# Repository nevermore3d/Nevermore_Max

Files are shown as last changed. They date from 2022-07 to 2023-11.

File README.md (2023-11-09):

<!--
*** Thanks for checking out the Best-README-Template. If you have a suggestion
*** that would make this better, please fork the repo and create a pull request
*** or simply open an issue with the tag "enhancement".
*** Thanks again! Now go create something AMAZING! :D
-->

<!-- PROJECT SHIELDS -->
<!--
*** I'm using markdown "reference style" links for readability.
*** Reference links are enclosed in brackets [ ] instead of parentheses ( ).
*** See the bottom of this document for the declaration of the reference variables
*** for contributors-url, forks-url, etc. This is an optional, concise syntax you may use.
*** https://www.markdownguide.org/basic-syntax/#reference-style-links
-->
# [Nevermore Stealthmax](https://github.com/nevermore3d/StealthMax) is the final Max release based on beta feedback, Please check it out!

Max had warping issues with many ABS type materials from the long straight components, which necessitated a frame redesign. This allowed for a built-in exhaust system too driven by the main fan, allowing well-insulated chambers not to overheat when printing PLA and PETG.

<BR><BR><BR><BR><BR><BR>
_300x300mm print bed minimum!_

**0.2 layers, 0.4 nozzle recommended [0.6+Aarachnae under evaluation]**

PRINTING GUIDE:

**FRAME:**

VERY WARP-PRONE WITH STANDARD ABS! Even if you never have warping issues otherwise, this is at the very edge of plastics cooling stresses. I have printed this successfully with TitanX, other users have had good results with ESun ABS+. As it will never be subject to PETG TG temperatures outside the chamber that can be a good option too. Extra adhesion precautions should be taken (lower z offset with horizontal compensation, nano adhesive, hotter bed or possibly chamber temps, etc). Also dont forget to **tape down your flex bed** or your flex bed may become the warping point instead.

**PANELS**

Panels have A LOT of surface area. If you do not use filament that pops off from the bed when cool - a need to flex your bed to remove parts - there is a certain risk that a thin PEI surface (0.15-0.30 mm thicknesses or therabouts) will be pulled off in spots with high adhesion, causing bubbles in your PEI. If you have thin PEI, or any other thin surface that can be damaged, please use a release layer between the print and bed (my simple household go-to for PEI+ABS is some corn starch dissolved in water and evaporated after being brushed onto the hot bed. Parts will release easily and any starch residue on the print or bed just washes off with water).

**Carbon Baskets**

The unbridged mesh extrusions keeping the pellets inside the filter are usually 0.4mm high and 0.8mm wide. They print best if the width is split in two lines (with some overlap, 0.4-0.46 should do it, check in your slicer) and the height is also split in two layers (allowing the first layer to be printed at a slightly lower extrusion multiplier as per bridging settings, and the second be a regular supported layer).

**Other parts**
The other parts should print like most other prints. 

**9/9: INSTALL GUIDE ADDED**
<!-- PROJECT LOGO -->
<br />
<p align="center">
  <https://github.com/0ndsk4/VoronUsers/tree/0ndsk4/printer_mods/0ndsk4/Nevermore_Air_Filter">
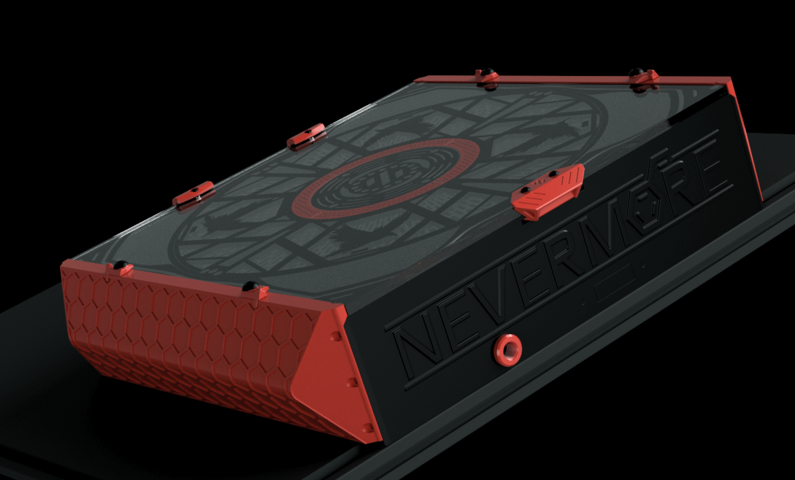
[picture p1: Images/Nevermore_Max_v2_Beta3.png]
    
							   <p align="center">
  <https://github.com/0ndsk4/VoronUsers/tree/0ndsk4/printer_mods/0ndsk4/Nevermore_Air_Filter">
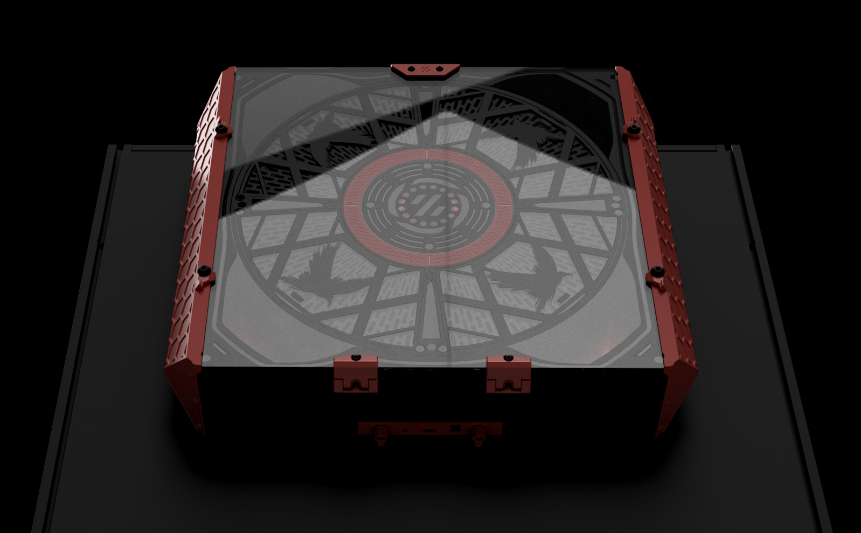
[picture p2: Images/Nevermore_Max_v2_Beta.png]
Angle
    
	  <p align="center">
  <https://github.com/0ndsk4/VoronUsers/tree/0ndsk4/printer_mods/0ndsk4/Nevermore_Air_Filter">
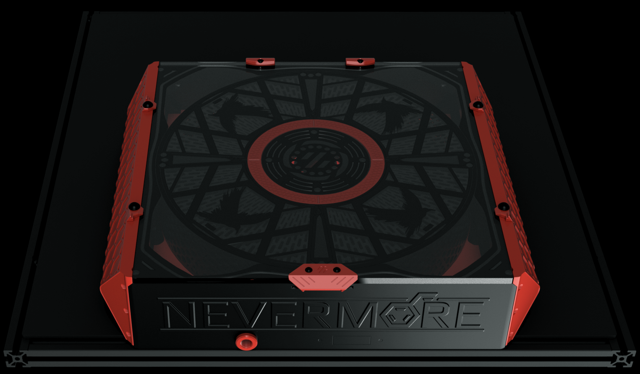
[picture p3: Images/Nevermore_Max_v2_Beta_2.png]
Angle2
    
  </a>

  <h3 align="center">Nevermore Max 3D printer Air Filter</h3>

<!-- TABLE OF CONTENTS -->
<details open="open">
  <summary>Table of Contents</summary>
  <ol>
    <li>
      <a href="#About-The-Nevermore">About: Why a Nevermore Max?</a>
      <ul>
        <li><a href="#Why">Why Nevermore?</a></li>
		<li><a href="#But-we-already-have-a-filtered-exhaust">But we already have a filtered exhaust?</a></li>
		<li><a href="#I-have-worked-with-plastics-and-I-am-fine">I've worked with plastics, and I'm fine!</a></li>
      </ul>
    </li>
    <li>
      <a href="#getting-started">Getting Started</a>
      <ul>
        <li><a href="#BOM">BOM and Sourcing Guide</a></li>
        <li><a href="#installation">Installation</a></li>
		<li><a href="#Built-with">Built with</a></li>
      </ul>
    </li>
    <li><a href="#contributing">Contributing</a></li>
    <li><a href="#license">License</a></li>
  </ol>
</details>

<!-- ABOUT THE PROJECT -->
## About Nevermore Max

Why a Max when the Micro works well? The little bugger is an easy print, nimble, looks great... Why bother making a large unit chewing filament?
			 
	 Well - there are a few reasons, that may or may not affect your decision on what filter is best for you.
			  
	1. We're **LAZY**. A micro cartridge is small and may not last very long. Some will 
	have filament smell again in two weeks.   And while the change is quick and easy,
	its still a chore! A Max has 20x the carbon. 20x the carbon lasts...longer.  
	
	2. We need **BETTER**. Carbon filtration gets better and better the deeper the carbon 
	bed. At the small airflow area of a micro, a deep bed quickly chokes air flow. 
	Ever wondered why a Micro XL cartridge is only 10mm longer than a standard cartridge? 
	Air flow degrades _that_ fast. The surface area of a micro cartridge is just 
	above 1000 mm2. A hefty max filter increases that over ten times at the inside 
	perimeter, and 50 times on the outside perimeter. This means the same powered
	fan could move _much_ more air at _less_ pressure drop.  
	
	3. We catch **PARTICLES**: 3D printer extrusion creates both VOCs and particles. 
	The micro focuses on VOCs, as thats what give off the worst smell and has direct 
	toxic effects, and are difficult to catch once outside of the print chamber. 
	Yet again, PM particles are among the leading causes of death in the world and 
	shouldn't be ignored. I've advocated using a regular room-size HEPA for particles 
	in conjunction with a micro before, but with the Max a HEPA filtration system is
	 built in. 99+ per cent of particles created by your printer will be removed 
	 every pass and you wont add dirty air to your room or lungs.  
	 
	4. We need **COOLER**: 3D printing and 3D printing filtration require different things.
	For instance, we _love_ to have a 60C chamber for less ABS warping. At the same
	time, with increasing heat, the VOCs get more heat energy and desorb from the 
	carbon. Sensor testing has shown that turning on a well used carbon filter can 
	_increase_ chamber VOCs. Anything above 50C is generally not good for bads stuff to
	stay attached to the carbon. And while the micro has been shown to work even at 
	80C intake air under a heated bed, it most definitely decreases the time between 
	carbon changes a lot! Having the filter unit outside of the printer allows for the
	carbon to be a few degrees cooler than the printer. That does much for longevity.  
	   
	5. We haz to needz **TECHz**: More space for cooler gadgets. Ever wondered when 
	its time to swap carbon? Well, on the max you could add VOC sensors to both intake
	and exhaust and measure how well the filter is doing its job! Thanks to Dr Dave
	there are even data on which sensors reliably detect the aromatic VOCs we strive
	to catch (a lot of sensors hardly detect extrusion VOCs at all as they are intended
	for other applications). I've chosen to divide the project into a Basic version
	with just HEPA+carbon+fan, but entirely upgradeable to the Pro version 
	including VOC sensors (temp, humidity, filter efficiency), LED/Screen
	/Controller board, servo carbon sealing for (optimal carbon longevity with no
	room VOC carbon depletion) and a 4010 exhaust (negative pressure+vent 
	control).  

	7. Less **NOISE**: Lets face it. A high powered 5015 creates some noise. Two creates
	even more. By increasing the size of the carbon filter, decreasing pressure drop,
	we can run the filter fan slower while still getting the same air flow. We can 
	run the fan at a higher rpm:s and clean the chamber in a jiffy as well.  
			    
			  Convinced? Well, then the Max is for you!	

<!-- GETTING STARTED -->
## Getting Started

You're ready to build a Nevermore? Cool! The New Max is a lot simpler to assemble compared to the first version!

### BOM and Sourcing Guide
For the sourcing guide, details and material list please check this out: [BOM](BOM.md)

Instead of ultra thin bolts, m3 lap top screws seems to work as well and are readily available (https://www.ebay.com/itm/185540026013?var=693379492797)

### Installation
The installation guide is under development, the alpha presentation  should take you 90% of the way:
[Installation Guide](https://www.canva.com/design/DAFLeYZF86Y/dYEmVobjTJoAHgrsha3OjA/view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)

### Built with
The Voron nevermore Air Filter was modelled in [Fusion 360](http://autodesk.com).

<!-- USAGE EXAMPLES -->

### Why

At the end of the day, a fresh single-pass filtered exhaust (at brand new) has perhaps 70% VOC removal efficiency while still exhausting 30% of the nasty into the air you breathe. A recirculation filter achieving four passes at worn-in 50% efficiency could still remove 94% of the bas stuff. Or 99% at six passes!

The number of passes you get all depends on how well you can seal your build chamber. The better sealed the chamber, the less room VOCs will circulate the carbon and deplete the filter too (VOCs from onions, wall paper or farts might not be as unhealthy as melted plastics VOCs, but they block space in the carbon all the same).

Some will have a hard time achieving a good chamber seal, which creates the biggest drawback of recirculation filters - they're air flow neutral. Meaning, as nothing pulls air into the chamber, air can diffuse freely to the outside through any remaining gaps. And that air could be <i>zero per cent</I> cleaned...

To both have the cake and eat it (yes you can!), a Max can incorporate a 4010 exhaust fan, that is used to keep a slight negative pressure inside the chamber - air will still just get pulled _into_ the chamber through any remaining cracks, not leak outside. Don't ramp it up high, its meant to just barely evict air so that the majority of air flow through the filter is still recirculated.

Air evicted through the exhaust will at least have passed through the carbon filter, dust-filter and HEPA filter at least once (hopefully many more times) - so its a good security measure to have if you don't want to bet on your chamber being hermetically sealed.

### But we already have a filtered exhaust?

Yup, but aside from being one-pass, regular mesh carbon filters mainly consists of...mesh. And active carbon sprinkle - miniscule amounts, not meant to be used 24/7 in a 3d printer.

Just running regular  air through a mesh filter will still deplete it in weeks (carbon can't opt to just bind the nasty stuff). Filter exposed to air depletes it too, in time. Friggin' everything depletes carbon. Thats why we need *more*.

<b>The Nevermore</B> has a <i>kilo</i>, or two pounds, of active carbon. Not single-digit grams. And its can be sealed off from the surroundings, so when its not running, its not depleting. Any off-gassing between prints will likewise be kept inside the filter! And when is does run, it has a lot of VOC binding capacity! At least a hundred times more compared to a generic solder fume carbon mesh filter. 

This is the filter for the low maintenence crowd (who still want to be safe).

### I have worked with plastics and I am fine!

If you live alone - not impacting other people – and feel that way, this filter is not for you! <br>
After all, you’re perfectly allowed to smoke two packs a day or become a opposition politician in Russia too, even though it’s probably not optimal for your health. And on an individual level one can never be sure what the health effects will be, if any - the oldest person ever used to smoke until she was 118 years or so…

But speaking of what we do know, we can say for sure that:<BR>

The WHO:s <I>International Agency for Research of Cancer (IARC)</i> classifies chemical compounds based on the known evidence of human carcinogenics, into four classes (<I>carcinogenic, probably carcinogenic, possibly carcinogenic or not classifiable as carcinogenic to humans</i>).<BR><BR>
Most chemicals fall into the last category, but in the known carcinogenic groups we find several known 3d printer byproducts:<br><br>
&nbsp;&nbsp;&nbsp;&nbsp;&nbsp;&nbsp;&nbsp;<B>o Benzene</b><BR>
One of the main fumes from ABS printing. 3ppm regarded as safe, whereas up to 280 ppm of VOCs are produced ABS printing every hour in a small space. Proven to cause different leukemias, and suspected of causing a multitude of other cancers. Female workers in a shoe factory exposed to 40ppm for a long time had a hundredfold higher risk of dying from breast cancer, for instance. Class 1 carcinogenic.<br><BR>
&nbsp;&nbsp;&nbsp;&nbsp;&nbsp;&nbsp;&nbsp;<b>o Styrene</B><BR>
Main pollutant in ABS fumes, recently upgraded from possible to probable carcinogenic based on mounting evidence of connection with a close to tripled risk of different leukemias.<br><BR>
&nbsp;&nbsp;&nbsp;&nbsp;&nbsp;&nbsp;&nbsp;<B>o Butadiene</b><BR>
Another component of ABS printing, and the reason why styrene didn’t get the carcinogenic label for so long (as both are ABS byproducts it was long impossible to know if a cancer type was due to butadiene or styrene. Butadiene is also a known cause and/or cofactor in cardiovascular disease, so you might get your heart attack or stroke a few years earlier by breathing it in for a long time.<br><br>
<u>Other knowns:</U><br><br>
&nbsp;&nbsp;&nbsp;&nbsp;&nbsp;&nbsp;&nbsp;• What creates the most particles/VOCs from plastics handling is <i>heated extrusion</i>.<br>
&nbsp;&nbsp;&nbsp;&nbsp;&nbsp;&nbsp;&nbsp;• Injection molding, vacuum forming and other common industrial methods creates less air pollutants due to less melted plastic surface per kg with direct air/oxygen access/airflow.<br>
&nbsp;&nbsp;&nbsp;&nbsp;&nbsp;&nbsp;&nbsp;• 3D printing extrusion takes this to another VOC creation level, as you’re extruding thin layer by thin layer, not trapping any of the extruded melted material from access to oxygen or airflow. Thus, per kilogram of product, it’s the most particle and VOC generating plastic process there is.<br>
&nbsp;&nbsp;&nbsp;&nbsp;&nbsp;&nbsp;&nbsp;• Home 3d printers are often used in places without industrial ventilation or industrial wet scrubbing. Indeed, a recent study showed that levels of VOC carcinogenics in plastics recycling plants using heated extrusion processes were mostly within safe limits. However, in surrounding residential homes of those safe-to-work plants, VOC levels were up to <B>42 times</b> the safe limits and consisted of the ventilated byproducts from the plastic plants, due to lower ventilation requirements in homes. The study showed a clear increased lifetime cancer risk, even for the workers in the plants.<br><br>

This is a short list of some key knowns, and only address the most common ABS fumes. Other materials have different VOCs. PETG for instance, releases Toluene, Acetaldehyde, Formaldehyde – all of which are known health hazards. Regular PLA and Nylons without additives are usually safer, but still release lower levels of acetone, methyl-methacrylate, and iso-butanol (PLA) and Propylene Glycol and Cyclopentanone (Nylon). Not all fumes are created equal.<br><br>

<!-- CONTRIBUTING -->
## Contributing

Please contribute! I'd like to incorporate VOC sensors, making the filter smart (running on low-noise mode at an acceptable VOC level, then ramp up at the end to clean more thoroughly before doors open).

<!-- LICENSE -->
## License

Distributed under GNU General Public License version 3.0 (GPLv3)

<!-- CONTACT -->
## Contact

0ndsk4#5933  - (http://discord.com/user/0ndsk4#5933) <BR>
Nevermore: [https://github.com/0ndsk4/VoronUsers/tree/0ndsk4/printer_mods/0ndsk4/Nevermore_Air_Filter](https://github.com/0ndsk4/VoronUsers/tree/0ndsk4/printer_mods/0ndsk4/Nevermore_Air_Filter)

<!-- ACKNOWLEDGEMENTS -->
## Acknowledgements
* [The Voron Dev Team](https://vorondesign.com/)

<!-- MARKDOWN LINKS & IMAGES -->
<!-- https://www.markdownguide.org/basic-syntax/#reference-style-links -->

[product-screenshot]: images/screenshot.png

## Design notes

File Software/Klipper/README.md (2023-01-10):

**Installation instructions**

* Copy sgp40.py and voc_algorithm.py to klippy/extras
* The printer.cfg syntax is as follows
```
[sgp40]

[temperature_sensor voc_exhaust]
sensor_type: SGP40
#i2c_mcu:
#   The name of the micro-controller that the chip is connected to.
#   The default is "mcu".
#i2c_bus:
#   If the micro-controller supports multiple I2C busses then one may
#   specify the micro-controller bus name here. The default depends on
#   the type of micro-controller.
#i2c_speed:
#   The I2C speed (in Hz) to use when communicating with the device.
#   The Klipper implementation on most micro-controllers is hard-coded
#   to 100000 and changing this value has no effect. The default is
#   100000.
# ref_temp_sensor:
# The name of the temperature sensor to use as reference for temperature
# compensation of the VOC raw measurement
# ref_humidity_sensor:
# The name of the temperatur sensor to use as reference for humidity
# compensation of the VOC raw measurement
```

**Example configuration**

The following is an example using a BME280 and SGP40 on both the intake and the exhaust.
The intake sensors are connected to GP12/GP13 bus on the Raspberry Pi Pico and the exhaust sensors
are connected to GP14/GP15.

```
[sgp40]

[temperature_sensor temp_intake]
sensor_type: BME280
i2c_mcu: pico
i2c_bus: i2c0d
i2c_speed: 400000

[temperature_sensor temp_exhaust]
sensor_type: BME280
i2c_mcu: pico
i2c_bus: i2c1d
i2c_speed: 400000

[temperature_sensor voc_intake]
sensor_type: SGP40 # Sensor on the top left
i2c_mcu: pico
i2c_bus: i2c0d
ref_temp_sensor: bme280 temp_intake
ref_humidity_sensor: bme280 temp_intake
i2c_speed: 400000

[temperature_sensor voc_exhaust]
sensor_type: SGP40 # Sensor on the right
i2c_mcu: pico
i2c_bus: i2c1d 
ref_temp_sensor: bme280 temp_exhaust
ref_humidity_sensor: bme280 temp_exhaust
i2c_speed: 400000
```

**Mainsail**

In order to display the full VOC sensor information in Mainsail, the following command needs to be run **once** in the mainsail directory:
```
grep -l additionalSensors * -R | xargs sed -i 's+additionalSensors=\[+additionalSensors=\["sgp40",+g'
```
This command will need to be rerun each time Mainsail is updated

**Sources**

The voc_algorithm.py module is a slightly modified version of the module found in the [Adafruit CircuitPython SGP40 repository](https://github.com/adafruit/Adafruit_CircuitPython_SGP40).

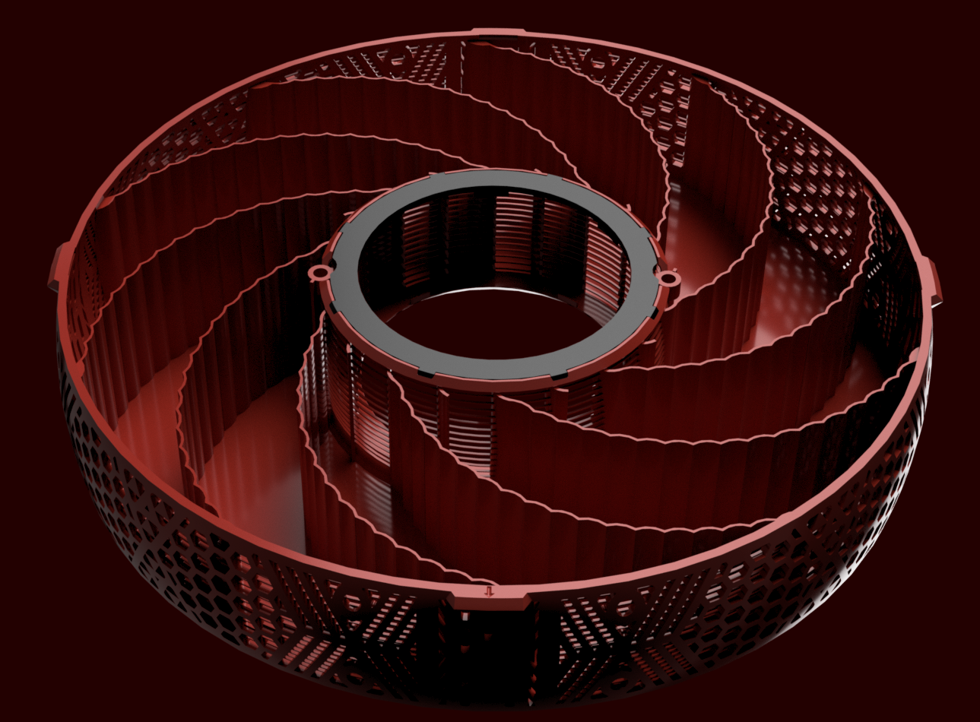
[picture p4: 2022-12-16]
Carbon_Baskets/High_Efficiency_Basket/High_Efficiency_Max_Basket.png

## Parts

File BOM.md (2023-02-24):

# BOM - Bill of Materials and Sourcing Guide
## BOM - Things you can buy
These are some examples on where you can buy those (in Germany). You can use different sellers or source everything elsewhere. We do not recommend these sellers or their products, and we are not related to them in any way. Before ordering, please make sure you covered the details for sourcing in the next section!
| Parts | Name | Link | Comment |
| --- | --- | --- | --- |
| Fans | DELTA BFB0712HF 65mm GPU fan | [https://aliexpress.com/item/1005002292969724.html](https://aliexpress.com/item/1005002292969724.html) | |
| | Sanyo 9TD12P6G001 | [https://www.mouser.de/ProductDetail/Sanyo-Denki/9TD12P6G001?qs=wnTfsH77Xs4c5b4Mut4mCw%3D%3D](https://www.mouser.de/ProductDetail/Sanyo-Denki/9TD12P6G001?qs=wnTfsH77Xs4c5b4Mut4mCw%3D%3D) | |
| Sealing | 2mm sponge cord | [https://aliexpress.com/item/1005002727229276.html](https://aliexpress.com/item/1005002727229276.html) | Shroud to frame seal |
| | 3mm sponge cord | [https://aliexpress.com/item/1005002727229276.html](https://aliexpress.com/item/1005002727229276.html) | Frame seal |
| | 5mm wide foam tape (1mm thick) | [https://aliexpress.com/item/32885016096.html](https://aliexpress.com/item/32885016096.html) | |
| | Transparent RTV (45gr.) | [https://aliexpress.com/item/1005002041941459.html](https://aliexpress.com/item/1005002041941459.html) | Shroud to frame seal |
| Bolts | SHCS M2x4 (8 pieces) | [https://aliexpress.com/item/1005001991188732.html](https://aliexpress.com/item/1005001991188732.html) | Electronics, Pro version |
| | (UltraThin) SHCS M2x6 (3 pieces) | [https://aliexpress.com/item/1005004288328345.html](https://aliexpress.com/item/1005004288328345.html) | Center fan |
| | SHCS M2.5x4 (8 pieces) | [https://aliexpress.com/item/1005001991188732.html](https://aliexpress.com/item/1005001991188732.html) | Electronics, Pro version |
| | BHCS M3x6 (22 pieces) | [https://aliexpress.com/item/4000896301219.html](https://aliexpress.com/item/4000896301219.html) | HEPA grilles, airflow guides |
| | BHCS M3x8 (20 pieces) | [https://aliexpress.com/item/4000896301219.html](https://aliexpress.com/item/4000896301219.html) | |
| | SHCS M3x6 (2 pieces) | [https://aliexpress.com/item/1005001991188732.html](https://aliexpress.com/item/1005001991188732.html) | |
| | SHCS M3x8 (4 pieces) | [https://aliexpress.com/item/1005001991188732.html](https://aliexpress.com/item/1005001991188732.html) | Airflow guides |
| | SHCS M3x10 (2 pieces) | [https://aliexpress.com/item/1005001991188732.html](https://aliexpress.com/item/1005001991188732.html) | Front panel hinges |
| | SHCS M3x12 (8 pieces) | [https://aliexpress.com/item/1005001991188732.html](https://aliexpress.com/item/1005001991188732.html) | Interconnect |
| | SHCS M3x16 (4 pieces) | [https://aliexpress.com/item/1005001991188732.html](https://aliexpress.com/item/1005001991188732.html) | Frame |
| | SHCS M3x20 (12 pieces) | [https://aliexpress.com/item/1005001991188732.html](https://aliexpress.com/item/1005001991188732.html) | |
| | SHCS M3x25 (6 pieces) | [https://aliexpress.com/item/1005001991188732.html](https://aliexpress.com/item/1005001991188732.html) | Front panel hinges, side shrouds |
| | SHCS M3x30 (12 pieces) | [https://aliexpress.com/item/1005001991188732.html](https://aliexpress.com/item/1005001991188732.html) | Side shrouds |
| | SHCS M3x40 (4 pieces) | [https://aliexpress.com/item/1005001991188732.html](https://aliexpress.com/item/1005001991188732.html) | Frame |
| | SHCS M3x65 (2 pieces) | [https://aliexpress.com/item/1005003149897309.html](https://aliexpress.com/item/1005003149897309.html) | Frame |
| | SHCS M3x70 (2 pieces) | [https://aliexpress.com/item/1005003666370655.html](https://aliexpress.com/item/1005003666370655.html) | Frame to extrusions |
| | UltraThin M3x6 (5 pieces) | [https://aliexpress.com/item/1005004288328345.html](https://aliexpress.com/item/1005004288328345.html) | Center fan |
| | UltraThin M3x8 (20 pieces) | [https://aliexpress.com/item/1005004288328345.html](https://aliexpress.com/item/1005004288328345.html) | |
| | SHCS M5x10 (4 pieces) | [https://aliexpress.com/item/1005001991188732.html](https://aliexpress.com/item/1005001991188732.html) | Twist latches |
| Hex nuts | M3 (4 pieces) | [https://aliexpress.com/item/1005002177898963.html](https://aliexpress.com/item/1005002177898963.html) | Front panel hinges, fan scroll |
| Heat inserts | M3, 5mm OD x 4mm height (>60 pieces) | [https://aliexpress.com/item/1005004047096275.html](https://aliexpress.com/item/1005004047096275.html) | |
| Magnets | 6x3 mm round magnets (4 pieces) | [https://aliexpress.com/item/1005001991968667.html](https://aliexpress.com/item/1005001991968667.html) | |
| Pro Stuff | 2x SGP40 VOC sensors | [https://aliexpress.com/item/4000037083952.html](https://aliexpress.com/item/4000037083952.html) | Electronics, Pro version |
| | 16 Neopixel ring | [https://aliexpress.com/item/2251832660443554.html](https://aliexpress.com/item/2251832660443554.html) | Electronics, Pro version |
| | 2x neopixels | [https://aliexpress.com/item/4000239230774.html](https://aliexpress.com/item/4000239230774.html) | Pro version |
| | DC power jack DC-005 (female 5.5x2.1mm) | [https://aliexpress.com/item/32955603696.html](https://aliexpress.com/item/32955603696.html) | Electronics, Pro version |
| | DC power jack male (5.5x2.1mm) | [https://aliexpress.com/item/33008559377.html](https://aliexpress.com/item/33008559377.html) | Electronics, Pro version |
| Carbon & Filters | Carbon | [https://www.fabreeko.com/products/nevermore-carbon](https://www.fabreeko.com/products/nevermore-carbon) | |
| | Filters  (4 pieces) | [https://aliexpress.com/item/1005001615722382.html](https://aliexpress.com/item/1005001615722382.html) | |

## Sourcing Guide

**PANELS**
* Front panel in 6mm or 1/4" transparent plastic. Polycarbonate, PET or *molded* Acrylic will work fine. 
Size depends on your material of choice for Max because of shrinkage factor. Actual measurements TBD (slightly smaller than 300x300mm).

* Mid and back panels are now 3D printed!

**FANS**

Center fan has two options:
* **Sanyo 9TD12P6G001** - the *expensive* choice. A 70x20mm radial blower capable of over 500Pa of static pressure or >40cfm, excellent build quality and made to work in up to 70C temperatures, as well as low noise capability. Its very pricey ($50), and has been hard to get hold of during the chip shortage
* **DELTA BFB0712HF 65mm GPU fan** - the *other* choice. Was originally made to push a lot of air through restrictive and hot 1060 graphics card coolers, and should hold upp well for this similar job. On Ali they go from as low as $5 up to about $15, and are thus a lot more affordable and practically always in stock. They also perform *almost* as well as the Sanyo.

**SEALING**

* *2-3mm* **neoprene/silicone/rubber *sponge cord*** (~2meters). The *soft and squishy kind*, Shore 00 range hardness (anything around 50 +-15 will work well). 
* *5mm* wide **closed cell foam tape** *or* **self expanding PU tape** (mainly for sealing of the back panel or possibly under the front panel if not using 3mm sponge cord - not too thick, made to cover a ~1mm gap or so).
* **RTV.** Preferably clear or in the color of your printed panels (or side shrouds, if not using 2mm sponge cord)

**BOLTS, HEAT INSERTS, HEX NUTS**

See table for all the required material. For the **ULTRA THIN HEAD** use Misumi CBSKE-8 or similar with flat head and head thickness <=0.8mm. For reference, a M3 SHCS bolt head is 3mm and a BHCS bolt head is 1.6mm. These are more difficult to source, therefore the linked ultra thin heads are 0.8 - 1mm.

**OPTIONAL ELECTRONICS**
Please note that they are only needed for the pimped up Pro version of the Max.

**CARBON and FILTERS**

* **Active carbon:** 4mm activated  carbon pellets. Pellets are preferred because they're less dusty and has lower pressure drop than granules (GAC). 4x6 mesh GAC is the most similar to 4mm pellets if thats what you can get hold of. 4x8 mesh and smaller will impact air flow due to higher pressure drop, but potentially increase filtering efficiency for air that *does* pass through.

  * When sourcing the *optimal carbon* for 3D printer VOC adsorbtion, look for ***virgin coconut*** or ***anthracite*** carbon, not wood/bitumen/charcoal/bamboo/lignin. Why are these better? Well, while there are certain high grade, say bituminous activated carbon, there are also even more low grade bituminous carbon. For virgin coconut and anthracite from a vetted supplier, you'd be hard pressed to get bad carbon for #D printer VOC filtration. Grade and porosity matters;
	* Porosity for each and every source varies greatly (i.e, for aquarium or moonshine use you want large *macroporosity* to filter larger impurities, like oils. For that reason, water/liquid use carbon  has a large macropore area, defined as >100nm. Printer VOCs are generally less than 0.5 nm, meaning that for optimal capture rate and efficiency we want carbon with a high *microporosity* ratio, defined as <1nm). 
	* A higher **iodine count** >1000 usually indicates at least some micro/mesoporosity, and a higher **hardness** (>95%) will create less dust in air filtration. CTC number doesn't translate well to our VOCs, but toluene/benzene adsorbtion - which sometimes is available - is a good metric. 
	* **Avoid acid washed carbon**. Residues from bad acid washed carbon have oxidized printers! Go for steam activated, non acid-washed. By not using pH treated carbon, you will also adsorb a larger range of gasses.  A blend of different pH adsorbants might be the best choice in the future, but is currently impossible to source from trustworthy manufacturers. Good acid washed carbon shouldn't inherently be harmful to the printer (the acids are supposed to should stay locked inside the carbon), but it will catch a lesser range of VOCs and there's always the risk of that bad batch that has lots of acid residue left - so its best to avoid.
	* **Don't wash carbon** meant for air filtration. You will just bind water and water electrolytes to the carbon, so even if you dry it afterwards you will have lost a noticable percentage of capacity. If you have dusty carbon, blow away the dust (for a micro cartridge, blowing harmonica style out a window is a good option).
  * **IMPORTANT**! Since first release the *varying quality carbon out there has become increasingly evident*. Users has both gotten bad carbon as well as outright dangerous stuff (in one case oxidizing most metal surfaces in a new Voron in minutes. Be sure to vet your carbon supplier! 
  * If you wish to *support the project* and get the best possible filtration at the same time, **Nevermore carbon** bags are available in several 3D printer shops and is a *safe* and optimal choice with the market leading filtration efficiency/longevity, and porosity optimized for 3D printing aromatic VOCs and use in Nevermore filters. Ther carbon comes *de-dusted* and *vacuum packed* to avoid shipping grinding and new dust generation, so you can use it right out of the bag with no pre-treatment. It also has the best adsorbtion specs of any carbon currently available on the market, up to **4x better** (*2x efficiency, 2x longevity*) compared to no-name carbon (surface area >1250, benzene adsorbtion up to 48pct.wt, CTC 80, ball pan hardness 98). The cost is the downside though, if you look for good suppliers you can probably find options that are 80% as good at 60% the cost;

* **HEPAs**
You will need four pieces, but you can safely buy multiples of that, they are cheap and you will have to replace the filters from time to time (when replacing the carbon).

**PRINTED PARTS**
* 300x300mm print bed minimum (the frame piece is a square 298mm by 278mm, so your printer needs to be able to print over the entire surface and watch out for any skirts extending more than 2 mm outside the print job if doing this on a 300 machine).
* This was developed with and for **ABS+** material. Regular ABS *may* work depending on your printer, chamber heat and settings, but can also create *a lot of unnecessary woes*! Printing a full bed size piece **will cause warping** in warp prone materials - hence do consider ABS+. I print in titanX - an ABS+ material - on PEI with no issues. Since this will be positioned outside the printer, there is also the option to print in other materials. While I wouldn't print this in PLA if you plan on filtering a hot chamber that might reach above 60-70C under certain circumstances, PETG is probably fine. 
	* I use 3 walls and 16% gyroid infill. It might be wise to go to 4%+40% - or even solid for maximum rigidity - but after several kilos of prototyping I'm minimizing waste...
	* **Parts shrinkage.**  If using shrinking materials like ABS/ABS+/etc, parts shrinkage could be a factor. Parts do not always shrink evenly, for instance the square frame shrinks very little as its supported from all sides, while I needed to make the printer intake/exhaust piece 1% longer (with titanX ABS+ type filament) to fit into the frame. The other pieces have been usable as is without shrinkage compensation.

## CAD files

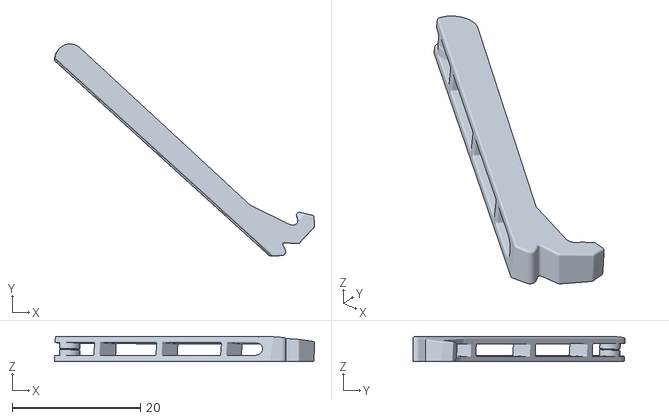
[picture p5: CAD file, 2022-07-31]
Carbon_Baskets/Dust_Filter_Latch_x4.stl
40.5 x 33.0 x 3.96

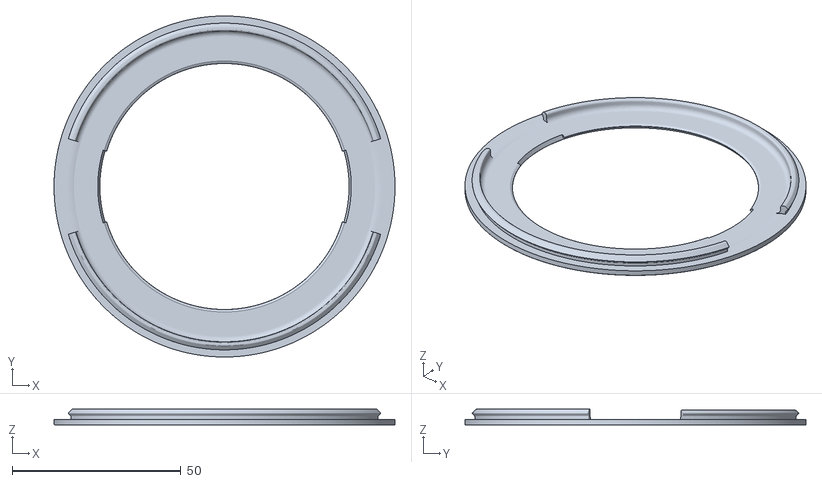
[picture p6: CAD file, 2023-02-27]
Center Hub (optional)/High_Efficiency_Hub/Hepa_Cover.stl
101.0 x 101.0 x 4.68

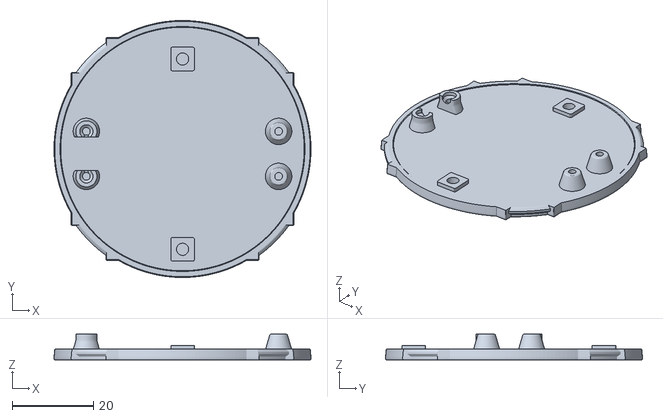
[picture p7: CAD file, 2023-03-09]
Center Hub (optional)/High_Efficiency_Hub/Hub_Cap_Options/Just_the_voron_Logo_Cap.stl
63.1 x 63.1 x 6.30

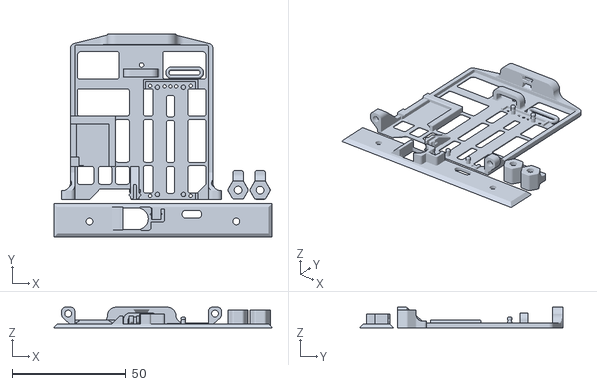
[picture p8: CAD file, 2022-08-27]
Electronics_Bay/Electronics_Bay_Pi_Pico_and_Mateksys_Micro_BEC_660.stl
95.6 x 89.1 x 9.20

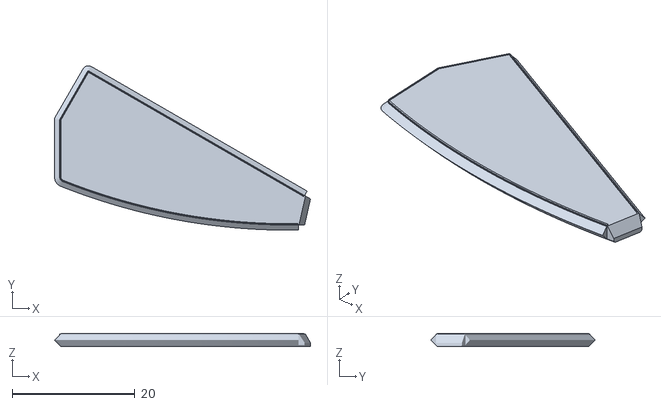
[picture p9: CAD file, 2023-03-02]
Fan_Scrolls/High_Efficiency/Sanyo_wire_path_cover.stl
41.7 x 26.8 x 2.11

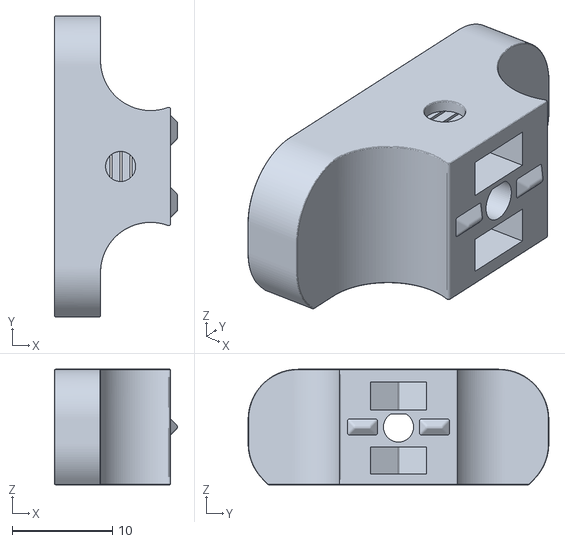
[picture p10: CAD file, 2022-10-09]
Fan_Scrolls/Magnetic_Latch.stl
12.3 x 30.0 x 11.5

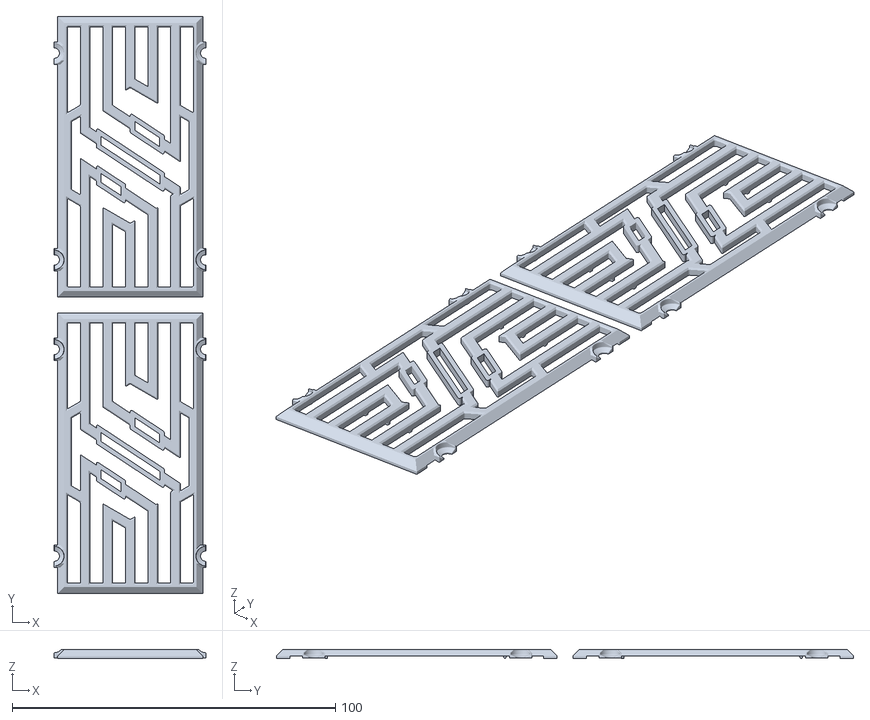
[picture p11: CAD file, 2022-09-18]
Frame/HEPA_Grills_2x.stl
46.9 x 178.6 x 2.80

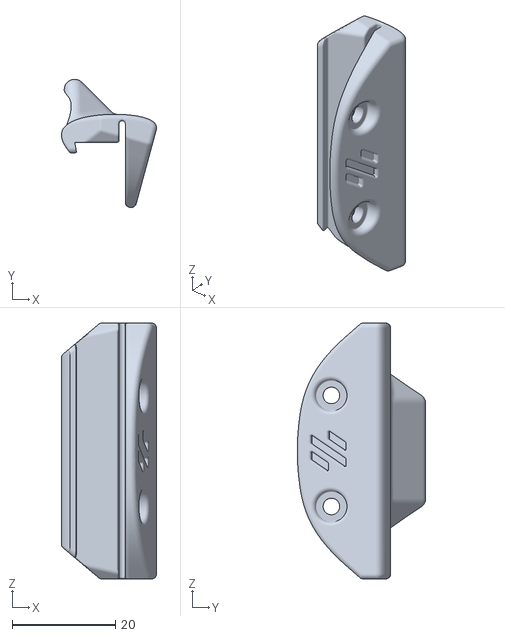
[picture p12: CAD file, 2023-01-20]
Front_Panels_Miscellaneous/Front_Panel_Front_Latch_new.stl
18.4 x 24.8 x 49.5

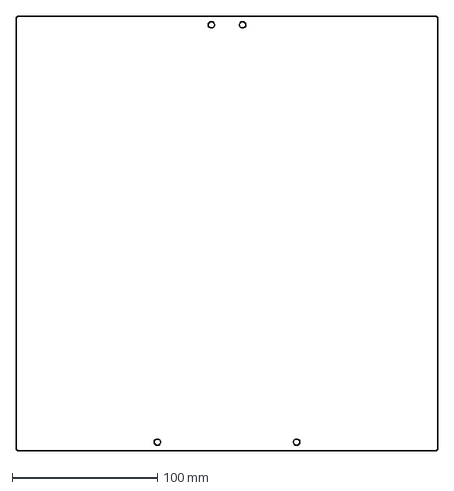
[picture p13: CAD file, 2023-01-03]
Printed_Panels/front_panel_scale_according_to_shrinkage.dxf
290.4 x 299.4 mm

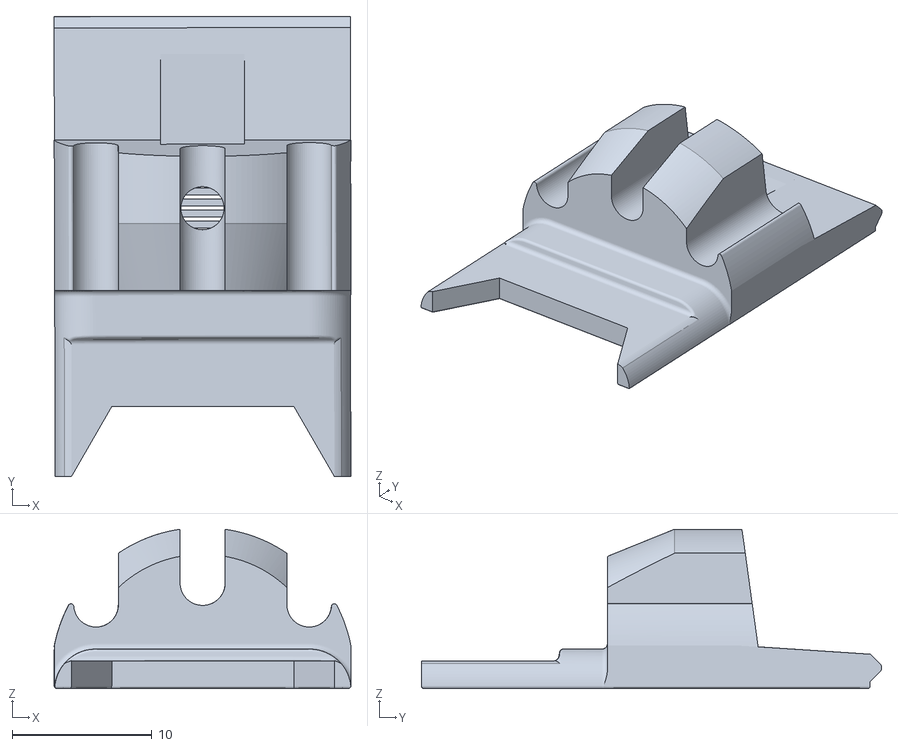
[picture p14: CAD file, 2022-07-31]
Carbon_Baskets/Carbon_Basket_Joiner_x4.stl
21.3 x 33.0 x 11.4

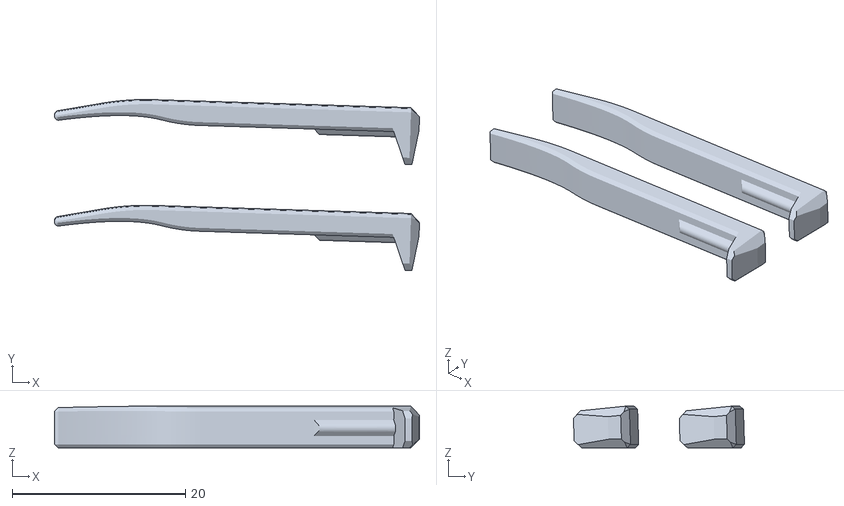
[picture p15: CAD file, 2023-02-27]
Center Hub (optional)/High_Efficiency_Hub/HEPA-Pryer_Tool.stl
42.1 x 19.7 x 4.82

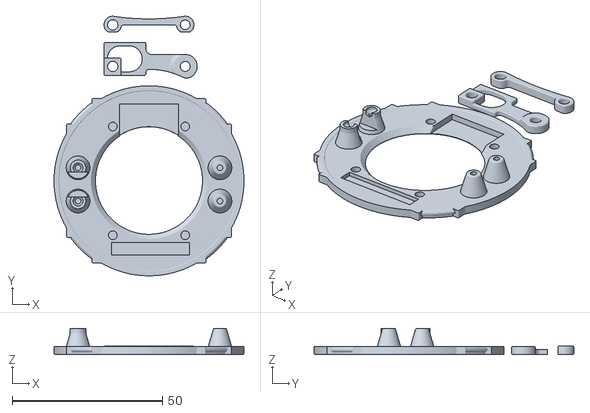
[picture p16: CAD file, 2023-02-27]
Center Hub (optional)/High_Efficiency_Hub/Hub_Cap_Options/gc9a01_1,3_LCD.stl
63.2 x 86.4 x 8.70

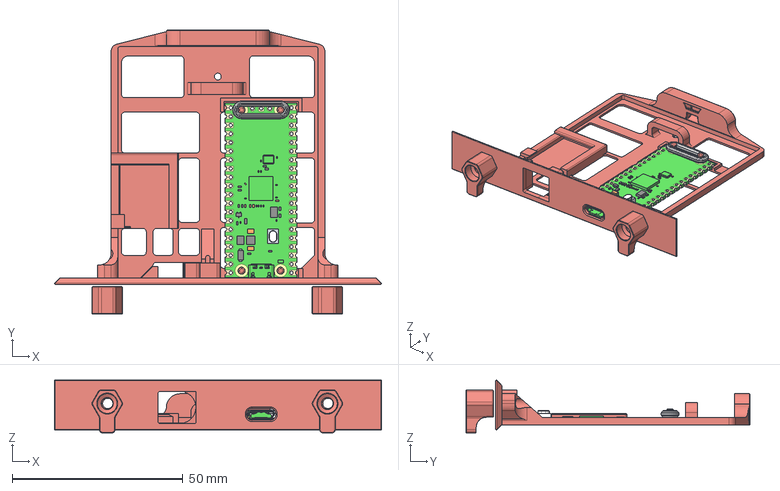
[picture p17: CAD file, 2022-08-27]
Electronics_Bay/Electronics_Slider_Pi_Pico_and_Micro_BEC6-60.step
95.6 x 83.1 x 15.5 mm

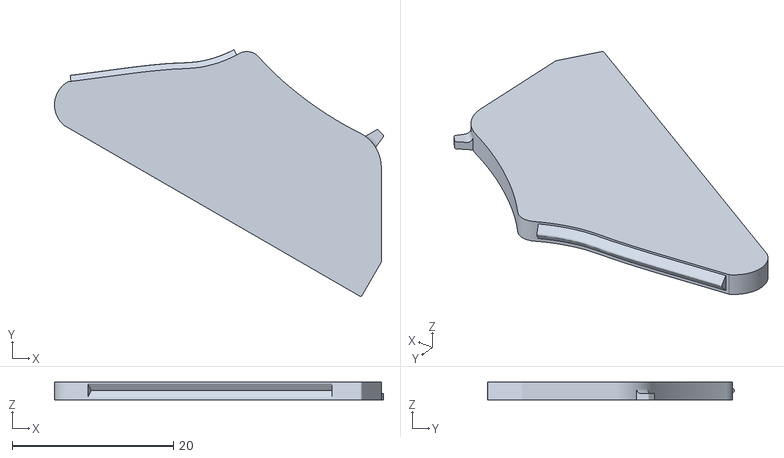
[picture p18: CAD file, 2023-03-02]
Fan_Scrolls/High_Efficiency/Delta_wire_path_cover.stl
40.8 x 30.6 x 2.20

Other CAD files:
Fan_Scrolls/Sanyo_C70x20.stl
Frame/Frame_Interconnect_1.stl
Front_Panels_Miscellaneous/Front_Panel_Twist_Latch_x2.stl
Printed_Panels/Back_Panel_SANYO_fan.stl
Fan_Scrolls/Air_Guides_and_bottom_crosslinks.stl
Fan_Scrolls/Fan_Scrolls.f3d
Fan_Scrolls/High_Efficiency/Fan_Scroll _Sanyo.stl
Frame/Frame_Interconnect_2.stl
Frame/Frame_Interconnect_3.stl
Front_Panels_Miscellaneous/Front_Panel_Back_Latch.f3d
Front_Panels_Miscellaneous/Front_Panel_Front_Latch_New.f3d
Front_Panels_Miscellaneous/Twist_Latch.f3d
Printed_Panels/BACK_PANEL_DELTA.f3d
Printed_Panels/BACK_PANEL_Sanyo.f3d
Printed_Panels/Back_Panel_DELTA_fan.stl
Printed_Panels/Can_You_Remove_the_Latch_Test_Print.stl
Printed_Panels/Mid_Panel.f3d
Printed_Panels/Mid_Panel_DaisyChainVOC_and_Less_Adhesion.f3d

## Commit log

2021-10-06 Move to new repo
    [5015 FanCovers.stl, Basket_Joiners.stl, Bottom_Panel_USB_DC.stl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]
2021-12-26 Add files via upload
    These are dxf files for the mid and back panels. Should be cut from 4.0mm material, color and choice optional. There’s a 0.1 negative tolerance in the files as it’s important the panels are not larger than specifications, but can be a few tenths smaller.
    [Both_Panel_4mm.dxf]
2022-05-03 Add files via upload
    fan scroll fixes
2022-05-04 Add files via upload
    6mm (.236) and 4.5mm (.177) panels
2022-05-24 Add files via upload
    This is a Nevermore Max fan scroll suited for an Orion 6015 (ODB6015-12HHB02A, 7,45CFM/20mmH2O)
    [fan_scroll_OBD6015.f3d]
2022-07-12 Add files via upload
    Frame and 2x frame bars to make a single Nevermore Max "unibody".
2022-07-12 Add files via upload
    without two bolt tabs that are only to make the filter hang straight for easier mounting, but extends the needed print area outside of 300x300mm.
2022-07-13 Add files via upload
    Side Shrouds. Due to warping tendency fused together to counteract warping to the sides. Cut apart with an x-acto knife and shave off residues of the joining.
2022-07-13 Add files via upload
    slides into the unibody frame to lock the middle panel. snap latches the last 2mms, so push it with some force once its almost in place
2022-07-15 Update README.md
    added BOM info
2022-08-01 Add files via upload
    Frame pieces in the same directory. Very minor change to frame to avoid a cut. Note that Frame_Interconnect_1 might need to scale 0.9% largerthan the rest of the pieces due to printing orientation.
    [Frame_Interconnect_1.stl, Frame_Interconnect_2.stl, Frame_Interconnect_3.stl]
2022-08-05 Add files via upload
    test if your printer will fuse the latch and mid panel! 0.2mm layers and good bridging settings a good start.
    [Can_You_Remove_the_Latch_Test_Print.stl]
2022-08-05 Add files via upload
    back panel that fits the sanyo fan
    [Back_Panel_SANYO_fan.stl]
2022-08-07 Add files via upload
    better fit for the center hub
    [Sanyo_C70x20.stl]
2022-08-07 Add files via upload
    old part had an errouneous fillet (diameter instead of radius)
    [Frame_Interconnect_1.stl]
2022-08-07 tolerance change
    tolerance change
    [Fan_Scrolls.f3d, Sanyo_C70x20.stl]
2022-08-08 orientation fixes
    orientation fixes
    [Front_Panel_Front_Latch.stl, V350_Front_Panel_Front_Latch.stl]
2022-08-20 Add files via upload
    These files will fit a Pi Pico W to control the Nevermore Max, as well as a Mateksys Micro BEC 6-60V for any (optional) voltage conversions between 24, 12 and 5V.
    [Electronics_Bay_Pi_Pico_and_Mateksys_Micro_BEC_660.stl, Electronics_Slider_Pi_Pico_and_Micro_BEC6-60.step]
2022-08-21 Add files via upload
    added the lost holes to make sure the fan scroll is air tight
    [BACK_PANEL_DELTA.f3d, BACK_PANEL_Sanyo.f3d]
2022-08-27 Create Frame.stl
    Two changes:
    1 - a misaligned supports on previous version
    2 - a change from 75mm m3 shcs bolts, to more easier accessible m3x70 and m3x65mm
2022-08-27 Sensor mounting points for Adafruit SGP sensors + removal of ultra thin head m3s
    1. Adafruit VOC sensors seem to be smaller than m3. Two pointing points per VOC sensor slot has thus been changed to m2.
    2. Removal of hard-to-find ultra thin head m3x8mm for the mid panel (changed to m3x6 bhcs)
    [Mid_Panel.f3d]
2022-09-09 Create Frame_300mm.stl
    added the 300mm version of the frame (same as the standard version, but lack two small hooks that might make mounting aligning i tiny bit easier. Both versions are functionality wise identical, but 3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
2022-09-13 added frame parts for in-chamber version
2022-09-14 adjusted ...
    mounting points and voc sensor latches for in-chamber version
2022-09-15 larger wire channel
    and optional xacto slot to open the wire channel for even more wire versatility)
    [Back_Panel_DELTA_fan.stl]
2022-09-15 higher wire channel (2.2mm, for awg 24 wiring)
    [BACK_PANEL_Sanyo.f3d, Back_Panel_SANYO_fan.stl]
2022-09-15 taller wire channels (2.2mm, for 24awg wires)
    [Mid_Panel.f3d]
2022-09-15 higher wire channel (2mm)
2022-09-17 0.6 nozzle improvement
    lowered raven "resolution" to print better with 0.6 nozzles, and fixed some bad surfaces
2022-09-18 hepa_grills
    2 grills in the stl (for one side of the frame). 4 grills needed for both sides.
    [HEPA_Grills_2x.stl]
2022-09-22 Mod for less bed adhesion and daisychain channels
    A printed panel has alot of bed adhesion, which can damage thin pei sheets. This version features less surface area for easier removal (if you have sticky prints consider adding a release layer top your print!), and edits the built-in channels for daisy chaining two SGP30/40 and two BME280 sensors, which - while possible - is trickier with the original mid panel.
    [Mid_Panel_DaisyChainVOC_and_Less_Adhesion.f3d]
2022-09-26 Split the main markdown file to separate BOM file, added links to the BOM (#1)
    * initial split of the BOM
    * updated BOM file
    * a bit of sync
    * fixed link to BOM from the TOC
    * verified material list, cosmetic changes
2022-09-26 Add files via upload
    .STEP of in-chamber version
2022-10-12 Even more small alignments
    * side shrouds could previously interfere with frame corner bolts in some cases
    * side shrouds interfered with hepa grill bolts (was also fixed in previous revision)
2022-10-12 fixed m3x40mm hole
    holes contained a bad surface in previous version that could cause cracking when tightening the frame bars to the frame with the m3x40mm bolts. bad surface is now removed, and the bolt holes now only thread the last 16mms.
2022-10-13 bolt hole corrected
    lateral bolt holes had one less top layer compared to center latches, meaning in certain settings a visible hole formed in the top mid panel. lateral latch bolt holes are now the same depth as the center bolt holes.
    [Mid_Panel.f3d]
2022-11-01 Update BOM.md
    Edited VOC sensor link
2022-12-15 Update Frame.stl
    support fix
2022-12-16 100% deeper carbon bed --> A lot higher efficiency, at the expense of air flow.
    the high efficiency basket increases carbon bed depth by almost 100%. This decreases pressure drop by much more. We are lucky the max baskets are very unrestrictive! Note: Requires a different center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
2023-01-10 Klipper module to support the SGP40 sensor (#4)
    * SGP40 sensor support for Klipper
    * Add empty readme
    * Update README.md
    [hepa_cover.stl]
2023-01-16 cable channels
    cable channels had disappeared in the previous version
2023-01-16 High Efficiency Center Hub
    High Efficiency Center Hub
    [Neopixel_Center_Top.stl, Neopixel_Holder_Cap.stl, Neopixel_screw.stl]
2023-01-20 replaces old latch
    replaces old latch that was stiff and would break when opening
    [Front_Panel_Front_Latch_New.f3d, Front_Panel_Front_Latch_new.stl]
2023-02-10 New High Efficiency Basket
    NM Max will move over to this one shortly. Compared with first effort, this has:
    * No space for filters (moved to the center hub)
    * Sturdier dividers (1.2mm instead of 0.8, and a thicker top for added stability)
    * Wider rim to sit more securely (like the original baskets), while still allowing airflow to enter 360.
2023-02-10 Add files via upload
    new high efficiency basket and lid stl
2023-02-24 Update BOM links (#6)
    * Remove .de from links
    * Fix markdown spacing
    * Fix remaining inconsistencies
2023-02-27 attachments
    Hepa Cover is a snap on cover that covers the hepas or dust filters in the hub.
    The pryer tools slide into the hub (beneath the hepa cover) and allows for easier removal of a spent xiaomi hepa.
    [HEPA-Pryer_Tool.stl, Hepa_Cover.stl]
2023-02-27 Add files via upload
    Currently lets you chose between two neopixel versions and a center gc9a01 lcd version
    [gc9a01_1,3_LCD.stl]
2023-03-02 Add files via upload
    adds matching wire paths and mounting points for the high efficiency hubs
    [Fan_Scroll _Sanyo.stl]
2023-03-02 Add files via upload
    small covers for the wire paths
    [Delta_wire_path_cover.stl, Sanyo_wire_path_cover.stl]
2023-03-09 Add files via upload
    a center hub cap with no electronics
    [Just_the_voron_Logo_Cap.stl]
2023-04-06 removed extra material
    was extra material blocking the lid, now fixed
2023-04-06 fixed the extra materials issue blocking the lid tab
2023-04-16 Added info about laptop screws # ultra thin
2023-11-18 Update sgp40.py (#7)
    * Update sgp40.py
    Added 'plot_voc' boolean to output only voc vs all parameters
    Added 'voc_scale' float to adjust the scale for voc output for plotting (e.g., 0.5)
    Added INITIALIZE to _init_sgp40
    Removed FEATURE_SET from _init_sgp40 - performs soft reset and results in "unable to write to i2c_device" error
    Removed SOFT_RESET - results in "unable to write to i2c_device" error
    Changed featureset output to 0x3200 from 0x3240 as per Adafruit discussion forums (https://forums.adafruit.com/viewtopic.php?t=202391)
    Added a correction for saturation vapor pressure with changing temperature to adjust humidity assuming initial humidity 50% with temperature 25C
    * Upd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
